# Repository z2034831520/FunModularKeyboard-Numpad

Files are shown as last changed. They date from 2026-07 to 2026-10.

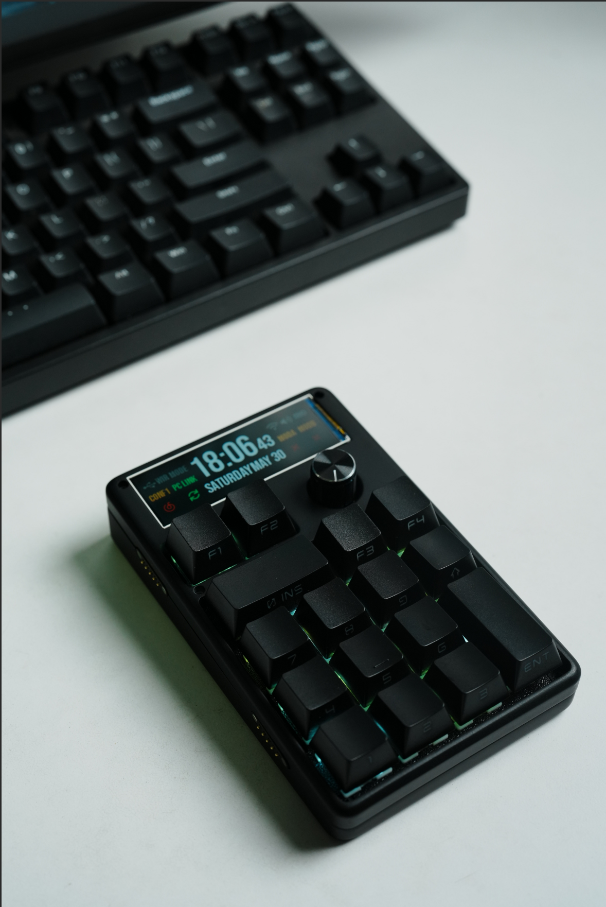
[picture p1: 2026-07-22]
doc/image2.png

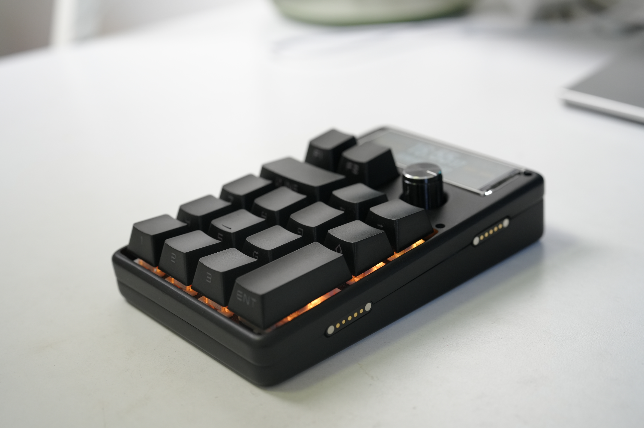
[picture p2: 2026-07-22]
doc/image4.png

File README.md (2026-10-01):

# FunModularKeyboard-Numpad — 独立宏键盘

> 这是 FunModularKeyboard 的独立数字小键盘版本，采用 ESP32-S3，保留可配置键位、屏幕、语音、USB/BLE HID 和 RGB 等功能。




## 🔀 Fork 说明

本项目 Fork 自 [ZhiFun/FunModularKeyboard](https://github.com/ZhiFun/FunModularKeyboard)，当前仓库为 [z2034831520/FunModularKeyboard-Numpad](https://github.com/z2034831520/FunModularKeyboard-Numpad)。

当前定制开发分支为 `standalone-numpad`，基于上游提交 `06c5d73` 继续开发。

该 Fork 目前专注于主机数字小键盘的独立使用。原项目的扩展模块源码和硬件资料仍保留在仓库中，但默认固件不启用这些模块。

### 当前 Fork 的修改

| 修改项 | 说明 |
|---|---|
| 禁用扩展模块 | 通过 `ENABLE_EXTENSION_MODULES=0` 关闭 ModA/ModB 的初始化、轮询和相关界面功能，使固件专注于主机数字小键盘。扩展模块代码未删除，后续仍可重新启用。 |
| 统一源码格式 | 对 `firmware/FunModularKeyboard/src` 下的 C/C++ 源码进行格式统一，不以改变原有功能为目的。 |
| 删除电量检测功能 | 移除 ADC 电压采样、电量估算、校准配置、低电量提示及诊断输出；状态栏不再显示电池图标和百分比。硬件充电功能不受影响。 |

---

屏幕截图 2026-07-19 162423

屏幕截图 2026-07-18 232027

屏幕截图 2026-07-18 231906

屏幕截图 2026-07-18 232058

屏幕截图 2026-07-19 162929

---

## 📖 项目概述

**FunModularKeyboard** 是一款高度可定制的宏键盘，由 **1 个主模块和 2 个磁吸扩展模块**组成。主模块通过磁吸 Pogo-Pin 接口与扩展模块进行 I²C 通信，并支持热插拔。

### 🧩 硬件架构

| 模块 | MCU | 说明 |
|---|-----|---|
| **主模块** | ESP32-S3 | TFT LCD 屏幕、16 键矩阵、旋转编码器、扬声器、MEMS 麦克风、锂电池、RGB LED 和磁吸主机接口 |
| **A 模块（ModA）** | STM8S103F3 | 3 个旋转编码器和 2 个滑动电位器，通过磁吸接口进行 I²C 通信 |
| **B 模块（ModB）** | ESP32-S3 | 基于 [SmartKnob](https://github.com/scottbez1/smartknob)，集成无刷电机旋钮、应变片按压检测和 LED 灯环，通过磁吸接口进行 I²C 通信 |

```
┌─────────────────────────────────────────────┐
│              主模块 (ESP32-S3)              │
│  ┌─────┐  ┌──────────┐  ┌────────────────┐  │
│  │ TFT │  │ 16 键    │  │   旋转编码器   │  │
│  │ LCD │  │ 矩阵     │  │    + 按键      │  │
│  └─────┘  └──────────┘  └────────────────┘  │
│  ┌─────┐  ┌──────┐  ┌──────┐  ┌─────────┐  │
│  │麦克风│  │扬声器│  │ RGB  │  │  电池   │  │
│  └─────┘  └──────┘  └──────┘  └─────────┘  │
│         ┌──────┐  ┌──────┐                  │
│         │ USB  │  │ BLE  │    双模 HID     │
│         └──────┘  └──────┘                  │
│       ══════ 磁吸 Pogo-Pin 接口 ══════       │
│           I²C + 电源 + UART                 │
├──────────────────┬──────────────────────────┤
│  A 模块 (STM8)   │  B 模块 (ESP32-S3)       │
│  3× 旋转编码器  │  无刷电机旋钮 (FOC)       │
│  2× 滑块        │  应变片按压检测          │
│                  │  8× LED 灯环             │
└──────────────────┴──────────────────────────┘
```

---

## ✨ 功能特性

### ⌨️ 键盘

- **8 套可切换键位配置** — 通过旋转编码器随时切换，适配不同工作流程
- **宏组合键** — 按下一个键即可触发多键组合，例如使用 `Ctrl+Win+D` 显示桌面
- **多媒体控制** — 支持播放/暂停、音量调节和切换曲目等操作
- **USB HID + BLE 双模** — 支持有线和无线两种连接方式

### 🎤 语音

- **语音指令** — 长按 MIC 键后说出指令，通过百度语音识别触发预设操作，例如“打开 Spotify”
- **语音转文字** — 将语音输入转换为文字并发送到电脑
- 支持自定义关键词与脚本的绑定关系

### 💻 桌面配套应用

桌面配置工具通过 WiFi/TCP 与键盘通信，支持以下功能：

- 🗺️ **可视化键位编辑器** — 通过拖放配置按键功能
- ⚙️ **设备设置** — 配置 WiFi、RGB 效果、屏幕亮度、主题和音量等参数
- 📜 **脚本引擎** — 支持 Python 脚本，可一键启动应用或执行桌面自动化
- 🔄 **固件 OTA 升级** — 通过无线网络升级键盘固件
- 📊 **电脑状态监控** — 在键盘屏幕上实时显示 CPU 使用率和磁盘空间等信息
- 🎵 **音乐歌词同步** — 播放音乐时同步显示歌词
- 🏠 **HomeAssistant 集成** — 预留智能家居控制接口

### 🎨 显示与灯效

- **TFT LCD + LVGL** — 提供丰富的图形界面和多主题支持
- **16 颗 WS2812B RGB LED** — 支持彩虹、火焰、流星和脉冲等灯效
- **音乐频谱可视化** — 实时显示 FFT 音频频谱动画
- **状态栏** — 显示连接模式、WiFi、音量和录音状态，不再显示电量

### 🧲 扩展模块

> 当前 `standalone-numpad` 分支已默认禁用扩展模块，以下为上游项目保留的硬件能力。

- **A 模块** — 配备 3 个编码器和 2 个滑块，适合调色、混音和视频编辑
- **B 模块** — 配备无刷电机旋钮（SimpleFOC）、触觉反馈和应变片按压检测
- 扩展模块通过磁吸接口实现**即插即用**和自动检测

---

## 📁 项目结构

```
FunModularKeyboard-Numpad/
├── firmware/                         # 固件源码
│   ├── FunModularKeyboard/           # 主模块固件（ESP32-S3、Arduino）
│   │   ├── src/                      # 核心源码
│   │   │   ├── main.cpp              # 程序入口
│   │   │   ├── MainTask.cpp/h        # 主任务调度
│   │   │   ├── DisplayTask.cpp/h     # LVGL 显示任务
│   │   │   ├── MatrixScanner.cpp/h   # 按键矩阵扫描
│   │   │   ├── RotaryEncoder.cpp/h   # 旋转编码器驱动
│   │   │   ├── RGBLightControl.cpp/h # RGB LED 灯效控制
│   │   │   ├── USBKeyboardImpl.cpp/h # USB HID 键盘实现
│   │   │   ├── BLEKeyboardImpl.cpp/h # BLE 键盘实现
│   │   │   ├── VoiceRecognizer.cpp/h # 百度 ASR 语音识别
│   │   │   ├── AudioAnalyzer.cpp/h   # FFT 音频频谱分析
│   │   │   ├── Mic.cpp/h             # MEMS 麦克风驱动
│   │   │   ├── Speaker.cpp/h         # 扬声器驱动
│   │   │   ├── SerialProtocol.cpp/h  # 上位机通信协议
│   │   │   ├── Configuration.cpp/h   # 配置文件管理
│   │   │   ├── Upgrade.cpp/h         # OTA 固件升级
│   │   │   ├── LogManager.cpp/h      # 日志系统
│   │   │   └── modules/              # I²C 主控与扩展模块
│   │   ├── data/                     # SPIFFS 数据文件
│   │   │   ├── config.ini            # 默认配置
│   │   │   └── keymap1~8.ini         # 8 套键位配置
│   │   └── platformio.ini            # PlatformIO 构建配置
│   ├── FunModularKeyboard_ModA/      # A 模块固件（STM8S103F3、IAR）
│   │   ├── main.c                    # 主程序
│   │   ├── ec11.c/h                  # EC11 编码器驱动
│   │   ├── adc.c/h                   # ADC 滑块采样
│   │   ├── i2c.c/h                   # I²C 从机通信
│   │   └── Uart.c/h                  # UART 调试输出
│   └── FunModularKeyboard_ModB/      # B 模块固件（ESP32-S3、PlatformIO）
│       └── firmware/src/             # 基于 SmartKnob 修改的固件
├── electronics/                      # PCB 设计（立创 EDA / EasyEDA）
│   ├── MainBoard/                    # 主板 PCB 工程
│   ├── ModA/                         # A 模块 PCB 工程
│   └── ModB/                         # B 模块 PCB 工程
├── cad/                              # 3D 机械结构文件
│   ├── Top.step / Bottom.step        # 主机外壳上下盖
│   ├── Plate.step                    # 轴体定位板
│   ├── Keycap.step / Keycap2.step    # 键帽
│   ├── FunModularKeyboard.3mf        # 3D 打印工程文件
│   ├── ModA/                         # A 模块外壳
│   └── ModB/                         # B 模块外壳
├── software/scripts/                 # 桌面自动化脚本
│   ├── desktop_automation_launch_apps_template.py  # 一键启动应用模板
│   └── desktop_automation_long_press_shutdown.py   # 长按关机脚本
├── tools/                            # 工具目录
└── README.md
```

---

## 🔧 技术栈

| 类别 | 技术 |
|---|---|
| **主控 MCU** | ESP32-S3（240 MHz、320 KB RAM、8 MB Flash） |
| **A 模块 MCU** | STM8S103F3 |
| **B 模块 MCU** | ESP32-S3 |
| **开发框架** | Arduino（PlatformIO）/ IAR（STM8） |
| **图形界面库** | LVGL 8.3 + TFT_eSPI |
| **键盘协议** | USB HID（TinyUSB）+ BLE HID |
| **语音识别** | 百度语音识别 API（REST） |
| **电机控制** | SimpleFOC 2.3 |
| **通信方式** | I²C（模块间）/ WiFi TCP（上位机） |
| **文件系统** | SPIFFS |
| **RGB 驱动** | FastLED（WS2812B） |
| **FFT 分析** | arduinoFFT |

### 主要库依赖

```
ESP32 BLE Keyboard    — BLE HID 键盘
FastLED               — RGB LED 控制
TFT_eSPI              — TFT 屏幕驱动
lvgl                  — 嵌入式图形界面框架
ESP32-audioI2S        — I²S 音频输入
SimpleIni             — INI 配置文件解析
ArduinoJson           — JSON 序列化
arduinoFFT            — 快速傅里叶变换
SimpleFOC             — FOC 电机控制
TLV493D               — 3D 磁场传感器
```

---

## 🚀 快速开始

### 主模块固件

1. 安装 [PlatformIO IDE](https://platformio.org/install)（VS Code 扩展）。

2. 克隆本 Fork 的 `standalone-numpad` 分支，然后进入主模块固件目录。

```bash
git clone --branch standalone-numpad https://github.com/z2034831520/FunModularKeyboard-Numpad.git
cd FunModularKeyboard-Numpad/firmware/FunModularKeyboard
```

3. 配置 WiFi 和百度语音 API 凭据（编辑 `data/config.ini` 或通过串口配置）。

4. 编译并烧录。

```bash
# 编译固件
pio run

# 烧录固件并上传 SPIFFS 数据
pio run --target upload
pio run --target uploadfs
```

### A 模块固件

使用 **IAR for STM8** 打开 `firmware/FunModularKeyboard_ModA/RGB_INIT.eww`，然后编译并烧录。

### B 模块固件

```bash
cd FunModularKeyboard-Numpad/firmware/FunModularKeyboard_ModB
pio run --target upload
```

> A/B 扩展模块固件由上游项目保留。当前独立数字小键盘模式不需要编译或烧录这两部分。

### 引脚参考

主模块的主要引脚分配如下，完整定义请参考 `platformio.ini` 和源码。

| 功能 | GPIO |
|---|---|
| LED 数据 | 6 |
| LED 电源 | 36 |
| 编码器 CLK | 5 |
| 编码器 DT | 21 |
| 编码器按键 SW | 9 |
| 电池电压 ADC（当前固件未使用） | 4 |
| I²C SDA | 15 |
| I²C SCL | 8 |
| 按键矩阵行 | 48, 10, 47, 33, 14 |
| 按键矩阵列 | 35, 34, 7, 13 |

---

## 🎮 使用指南

### 键位配置

1. 通过 WiFi 连接桌面配套应用。
2. 使用可视化拖放编辑器为每个按键分配功能，包括单键、组合键、宏和媒体控制等。
3. 最多可配置 8 套键位方案，长按旋转编码器即可切换。

### 语音功能

1. 在配套应用中配置百度 API Key 和 Secret Key。
2. 长按映射为 MIC 的按键开始录音。
3. 系统将识别结果与预设关键词匹配，并触发对应脚本。

### 固件升级

1. 配套应用通过 WiFi 将新固件推送到键盘。
2. 键盘自动重启进入 OTA 模式并完成升级。

---

## 🏗️ 硬件制作

- **PCB**：使用[立创 EDA](https://pro.lceda.cn/) 打开 `electronics/` 目录下的 `.epro2` 工程文件。
- **3D 外壳**：`cad/` 目录中提供 STEP 机械结构文件和可直接打印的 3MF 文件。
- **磁吸接口**：使用 Pogo-Pin 弹簧触点，用于模块间的 I²C 通信和供电。

---

## 📝 开发计划

- [ ] 开源桌面配套配置应用
- [ ] 接收社区贡献的扩展模块
- [ ] 完整集成 HomeAssistant
- [ ] 支持宏录制与回放
- [ ] 支持更多语音识别引擎
- [ ] 完善英文项目文档

---

## 🤝 参与贡献

欢迎提交 Issue 和 Pull Request。如果你设计了有趣的扩展模块，也欢迎在这里分享。

---

## 🙏 致谢

- [ZhiFun/FunModularKeyboard](https://github.com/ZhiFun/FunModularKeyboard) — 本 Fork 的上游项目
- [SmartKnob](https://github.com/scottbez1/smartknob) — 优秀的开源触觉反馈旋钮项目
- [LVGL](https://lvgl.io/) — 轻量级嵌入式图形界面库
- [PlatformIO](https://platformio.org/) — 跨平台嵌入式开发生态
- [百度语音识别](https://ai.baidu.com/tech/speech) — 中文语音识别服务

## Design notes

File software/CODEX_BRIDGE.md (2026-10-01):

# 键盘与桌面 Codex 双向互动

键盘通过主板串口发送动作，电脑端 `codex_bridge.py` 再通过本机 Codex App Server
创建线程和任务。桌面 Codex 的生命周期 Hook 通过本机 UDP 将运行、审批与完成状态
发送给桥接器，再由桥接器统一回传到 LCD 和 RGB 灯效。

## 全局安装（推荐）

在仓库根目录运行：

```powershell
powershell -ExecutionPolicy Bypass -File software\install_codex_bridge.ps1
```

安装程序会把桥接器复制到 `%USERPROFILE%\.codex\keyboard-bridge`，将用户级 Hook
安装到 `%USERPROFILE%\.codex\hooks.json`，并注册登录自启动任务
`FunModularKeyboard Codex Bridge`。计划任务会直接托管桥接进程，并在异常退出后每分钟
自动重试。用户级 Hook 会覆盖所有 Codex 工作目录；首次安装或
Hook 内容变化后，需要在 Codex 中打开 `/hooks` 审核并信任新的用户级 Hook。

如果登录后桥接器没有运行，可直接双击仓库根目录的
`start_codex_keyboard_bridge.cmd`。它会复用同一个计划任务，避免重复启动，并在失败时显示
错误。运行日志保存在 `%USERPROFILE%\.codex\keyboard-bridge\logs\codex_bridge.log`。

Hook 会把每个会话的 `cwd` 一并发送给桥接器。LCD/RGB 会汇总所有项目的任务状态。
K10 会通过 Windows 注册的 `codex://threads/new` 链接打开桌面 Codex 的新任务页；
串口号默认通过 `CX<PING`/`CX>PONG` 协议自动探测，因此
CH340 的 COM 编号变化后通常不需要重新配置。

仓库自身的 `.codex/hooks.json` 可以保留，方便其他用户直接使用。当前仓库同时加载
项目级与用户级 Hook 时会出现重复事件，但桥接器会按会话和轮次去重，不会重复计算任务。

## 默认按键

| 按键 | 动作 |
| --- | --- |
| K10 | 唤起桌面 Codex，并打开一个用户可见的新任务页 |
| K11 | 暂停当前桥接器任务 |
| K12 | 同意当前唯一一项待审批操作；没有待审批时无效 |
| K13 | 拒绝待审批操作；没有待审批时无效 |
| K14 | 在原线程中继续被暂停的桥接器任务 |

旋钮默认仍控制电脑音量：旋转调节音量、短按静音。长按旋钮约 0.7 秒可在音量模式和
Codex 思考等级模式之间切换；进入思考等级模式后，旋转会按照当前模型实际支持的等级
循环切换，短按旋钮也会切换到下一个等级。没有 `E:` 标记时，旋钮处于音量模式。

旋钮通过 Codex App Server 保存用户级默认 `model_reasoning_effort`，并读取当前工作目录下
的有效本地配置。这只能证明磁盘配置已更新，不能证明桌面 GUI 的等级选择器或正在运行的
任务已经改变。项目级配置等更高优先级设置可能覆盖用户级默认值。

K10 打开新任务页后，仅在没有已知运行任务时尝试通过 Windows UI Automation 的语义控件
选择等级，并重新读取模型与等级进行确认。不会点击固定坐标、自动提交任务或操作审批。
找不到唯一的模型和等级控件时会放弃自动控制，保留任务状态及 RGB 联动。
启动、旋钮选择及周期检查只读取 GUI，不会自动修改已有任务的选择器。

思考等级模式下，`E:?` 表示桌面端等级尚未确认；只有处于 READY 且当前 GUI 选择器的模型
和等级均匹配时，才显示 `E:HIGH` 等标记。此标记仍不证明任务运行时实际使用的等级。
运行中的 GUI 任务不提供可核验的等级字段，因此显示 `E:?`，LCD/RGB 继续汇总任务状态。
若当前桌面版本无法识别控件，请手动在桌面新任务页选择等级，不要仅依据磁盘配置判断生效。

上述 `E:?` 语义需要配套固件：旧固件在状态消息省略等级时会保留旧等级，并导致桥接器
收不到匹配回执而重发。更新桥接脚本后还需烧录修正后的固件；没有烧录时请以电脑端报告
为准，不要把 LCD 上残留的等级当作确认结果。

可从仓库根目录执行只读兼容性检查（不打开串口、不修改桌面）：

```powershell
py software\codex_bridge.py --desktop-probe --probe-model gpt-5.6-sol --probe-effort high
```

查看旋钮选择、本地有效配置和 GUI 确认结果：

```powershell
powershell -ExecutionPolicy Bypass -File software\show_codex_effort.ps1
```

加 `-Watch` 可持续查看。报告保存于 `%USERPROFILE%\.codex\keyboard-bridge\effort-state.json`。
`saved_host_hint` 只是桌面保存的主机提示，不是当前任务执行位置的证据；
`RuntimeVerified` 当前始终为 false。启动桥接器时加 `--no-desktop-sync` 可关闭 GUI 检测与尝试，
不影响 Hook 状态联动。

开发回归检查：`py -B -m unittest software/test_codex_bridge.py software/test_codex_desktop.py`。
串口固件回归测试位于 `software/tests/codex_serial`，使用模拟串口编译实际的
`CodexSerialBridge.cpp`，验证旧等级清除、回执、心跳和断连语义，不需要连接硬件。

## 使用方法

1. 确认桌面 Codex 已登录，并且 PowerShell 中执行 `codex --version` 能找到 Codex CLI。
2. 将键盘设为有线模式，烧录固件，并单独上传 `data` 分区，让 `keymap1.ini` 的映射生效。
3. 安装 Python 依赖：

   ```powershell
   py -m pip install -r software\requirements-codex-bridge.txt
   ```

4. 关闭占用键盘 CDC 串口的串口监视器，然后从仓库根目录启动桥接器：

   ```powershell
   py software\codex_bridge.py --port COM50
   ```

   请把 `COM50` 替换成主板 CH340 当前对应的端口。当前固件的烧录与 Codex
   通信共用该端口，因此启动桥接器前必须关闭 PlatformIO 串口监视器；需要重新
   烧录时，也必须先退出桥接器释放串口。

5. 重新打开 Codex 桌面端中的项目。首次加载 `.codex/hooks.json` 时，在 Codex 的
   Hook 管理界面审核并信任这些项目级 Hook。Hook 未被信任时，键盘按键发起的任务
   仍可联动，但桌面端主动发起的任务不会回传状态。

桥接器通过 App Server 发起的分析、审查等任务默认限制在当前仓库，使用
`workspace-write` 沙箱、`on-request` 审批，并关闭任务网络访问。LCD 显示
`CODEX READY` 后才接受任务键。K10 不再创建后台 App Server 任务，而是直接打开桌面
Codex 的新任务页；输入任务并发送后，Hook 才会让 LCD/RGB 进入运行状态。若本机未注册
`codex://` 链接，K10 会显示错误状态。`--no-open-app` 只关闭桥接器线程的自动展示，
不会禁用 K10 的桌面新任务入口。

可先执行不连接硬件、不启动 App Server 的配置检查：

```powershell
py software\codex_bridge.py --dry-run
```

`codex_tasks.json` 中的 `RESUME` 可以修改 K14 对应的提示词。K10 只打开桌面新任务页，
不会自动填入或提交提示词。桥接程序必须保持运行；退出后 LCD
会在心跳超时后显示 `CODEX OFF`。

桌面端 Hook 默认向 `127.0.0.1:18765` 发送状态。若端口被其他程序占用，可用
`--hook-port` 修改桥接器监听端口，并在 `.codex/hooks.json` 的命令中为
`codex_status_hook.py` 传入相同的 `--port`。Hook 不直接打开串口，因此不会与桥接器
争用 COM50。

桌面端任务的审批灯效只用于提示。K12/K13 仍只能处理由键盘桥接器自身发起的审批；
桌面端发起的审批需要在桌面 Codex 中确认或拒绝。

## RGB 状态

| Codex 状态 | RGB 灯效 |
| --- | --- |
| 已连接并待机 | 青色呼吸 |
| 正在运行 | 蓝色流水 |
| 等待审批 | 橙色闪烁 |
| 任务暂停 | 黄色双闪，保持到 K14 继续或 K10 新建任务 |
| 任务完成 | 绿色常亮，随后恢复青色呼吸 |
| 发生错误 | 红色快速闪烁 |
| 桥接器断开 | 恢复键盘原有 RGB 配置 |

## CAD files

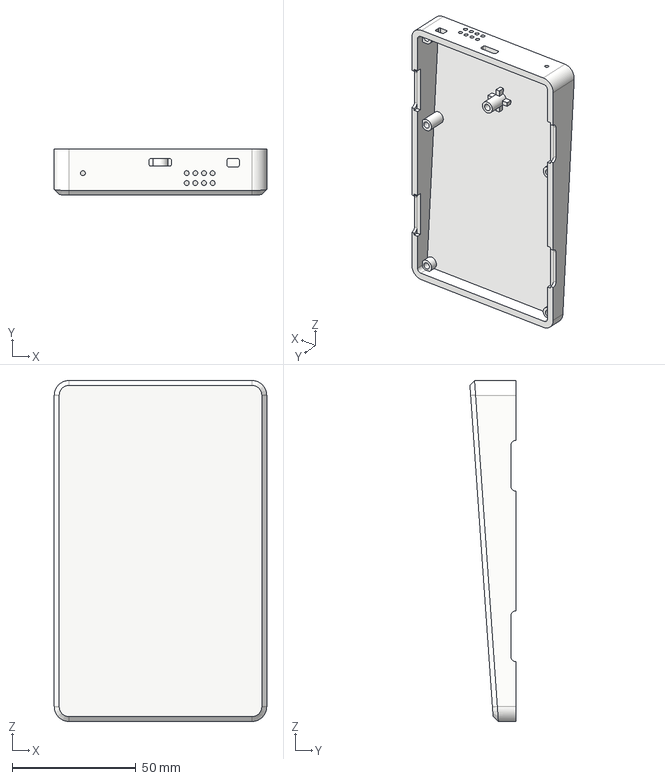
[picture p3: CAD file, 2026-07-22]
cad/Bottom.step
86.0 x 18.7 x 138.0 mm

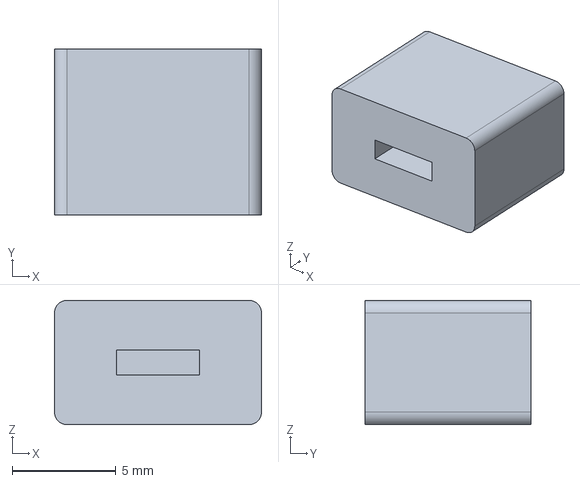
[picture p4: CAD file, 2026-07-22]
cad/ModA/Slider_Hat.step
10.0 x 8.00 x 6.00 mm

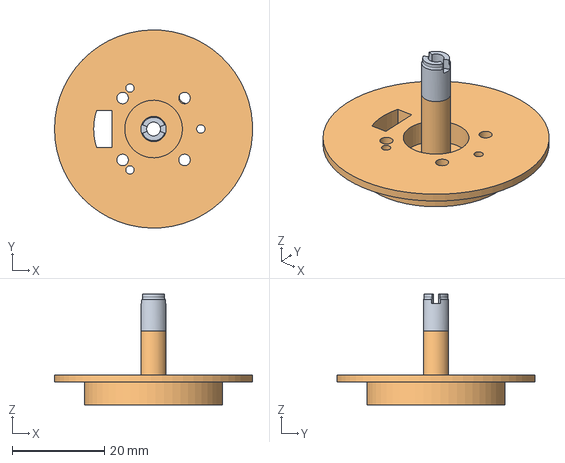
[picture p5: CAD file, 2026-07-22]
cad/ModB/MountBase_mod.step
43.0 x 43.0 x 24.0 mm

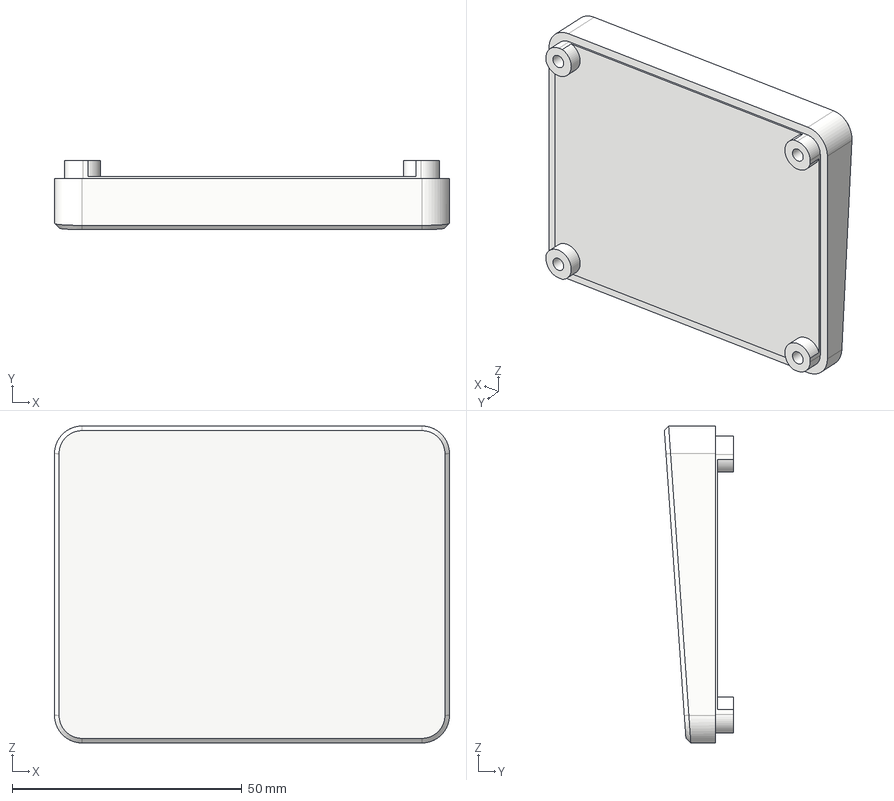
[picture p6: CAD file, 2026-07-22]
cad/ModA/ModA_Bottom.step
86.0 x 15.1 x 69.0 mm

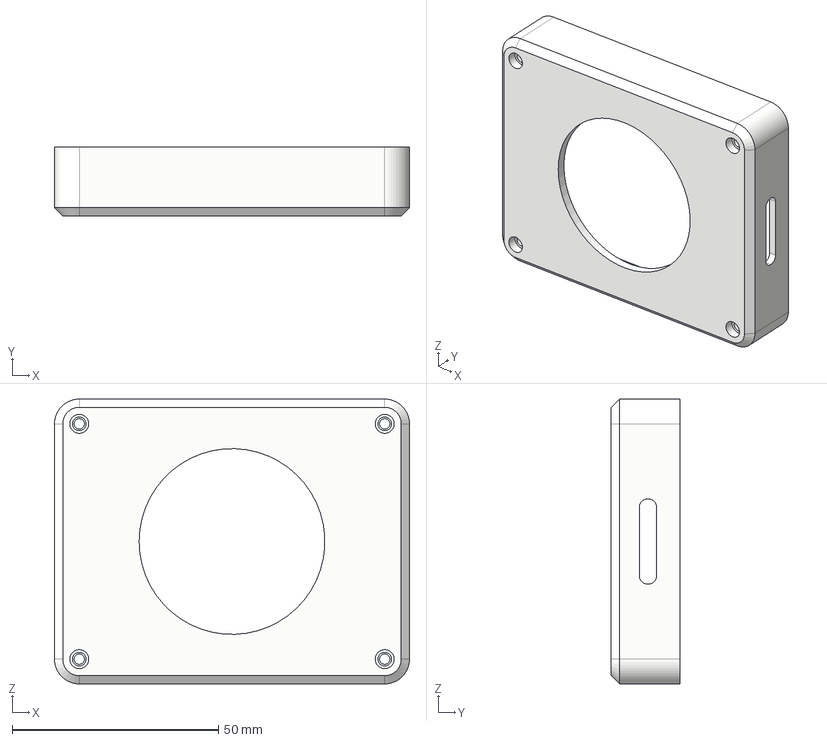
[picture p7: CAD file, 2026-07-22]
cad/ModB/ModB_Top.step
86.0 x 16.6 x 69.0 mm

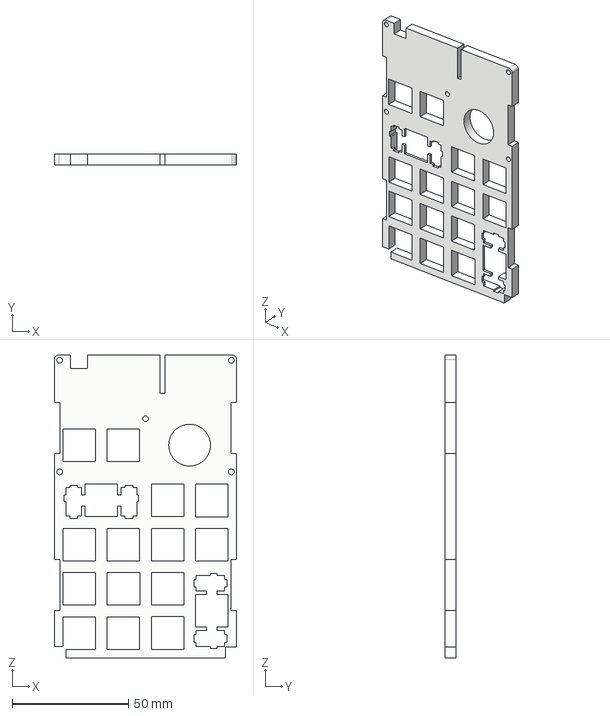
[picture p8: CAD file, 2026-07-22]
cad/Plate.step
78.6 x 4.80 x 130.6 mm

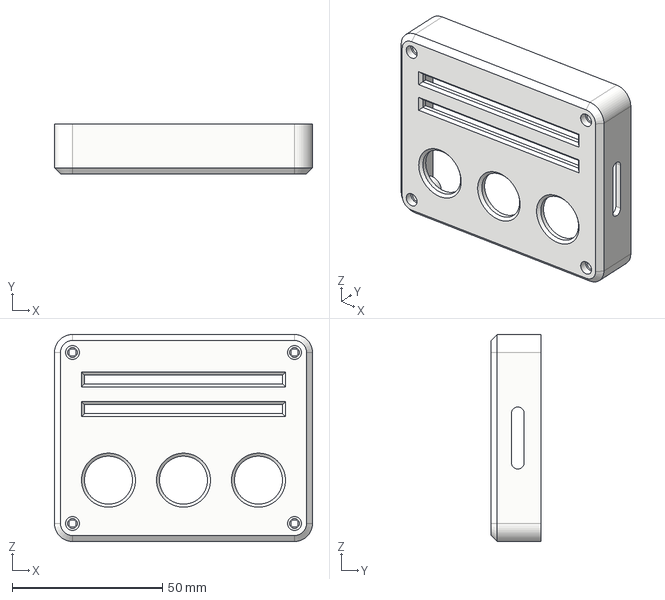
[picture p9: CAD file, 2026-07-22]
cad/ModA/ModA_Top.step
86.0 x 16.6 x 69.0 mm

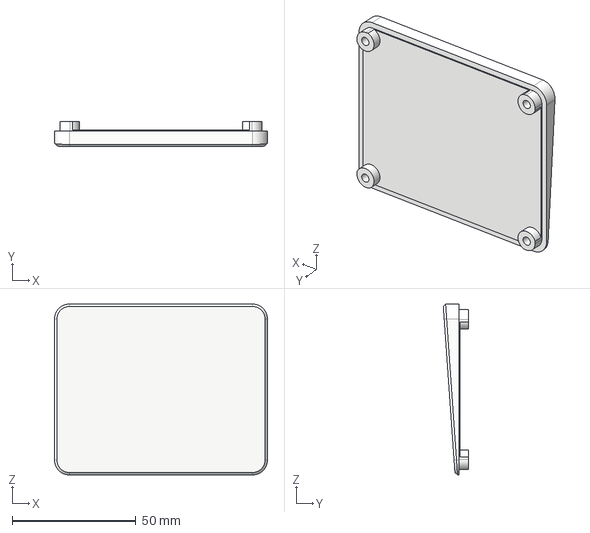
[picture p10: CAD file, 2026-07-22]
cad/ModB/ModB_Bottom.step
86.0 x 10.3 x 69.0 mm

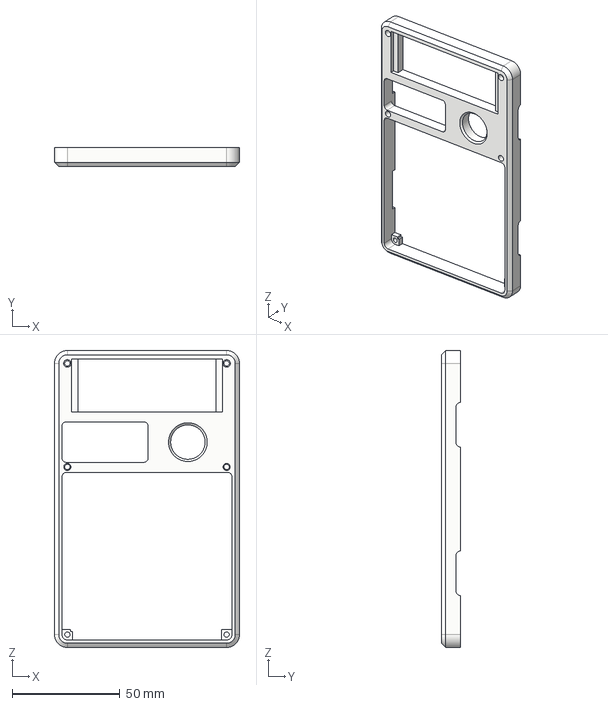
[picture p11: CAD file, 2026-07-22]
cad/Top.step
86.0 x 8.90 x 138.0 mm

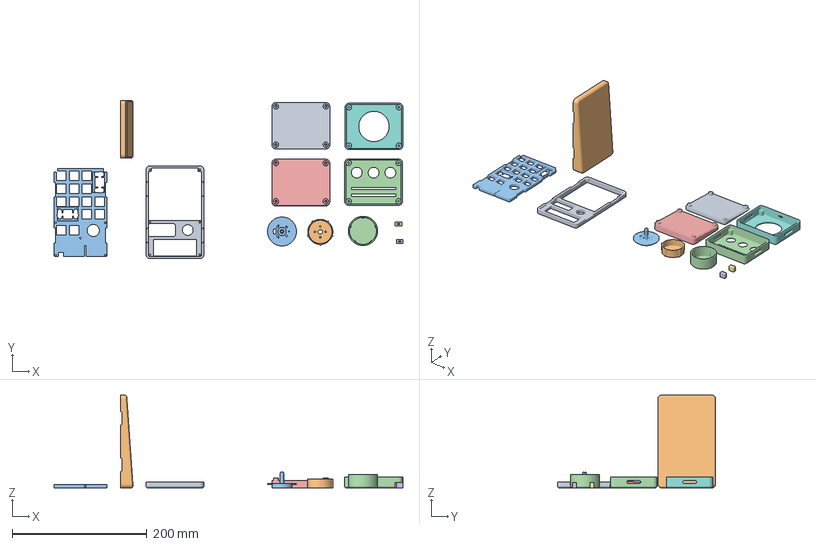
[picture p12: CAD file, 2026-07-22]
cad/FunModularKeyboard.3mf
518.1 x 235.2 x 138.0 mm
Top.step
Bottom.step
Plate.step
ModA_Top.step
ModA_Bottom.step
Slider_Hat.step x 2
ModB_Top.step
ModB_Bottom.step
MotorBase.step
MountBase_mod.step
ModB_Hat.step

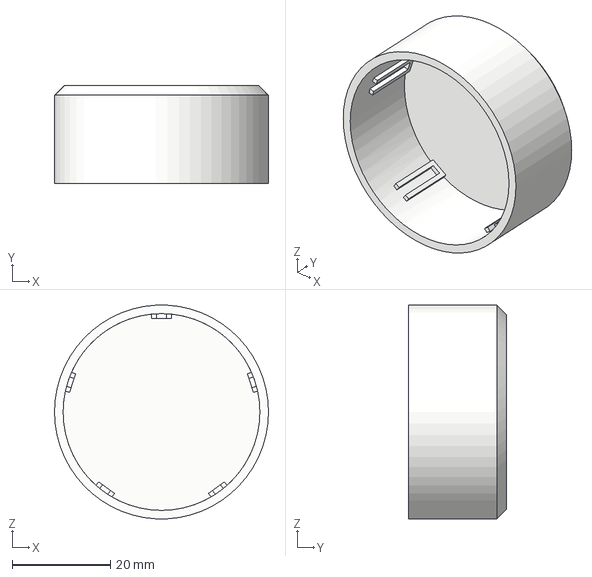
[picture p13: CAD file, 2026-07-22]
cad/ModB/ModB_Hat.step
43.5 x 20.0 x 43.4 mm

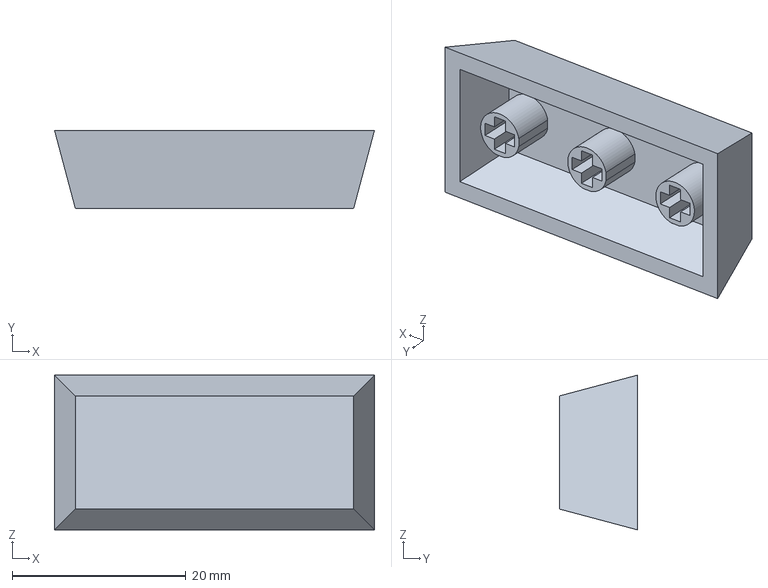
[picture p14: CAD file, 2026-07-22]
cad/Keycap2.step
36.8 x 9.00 x 17.8 mm

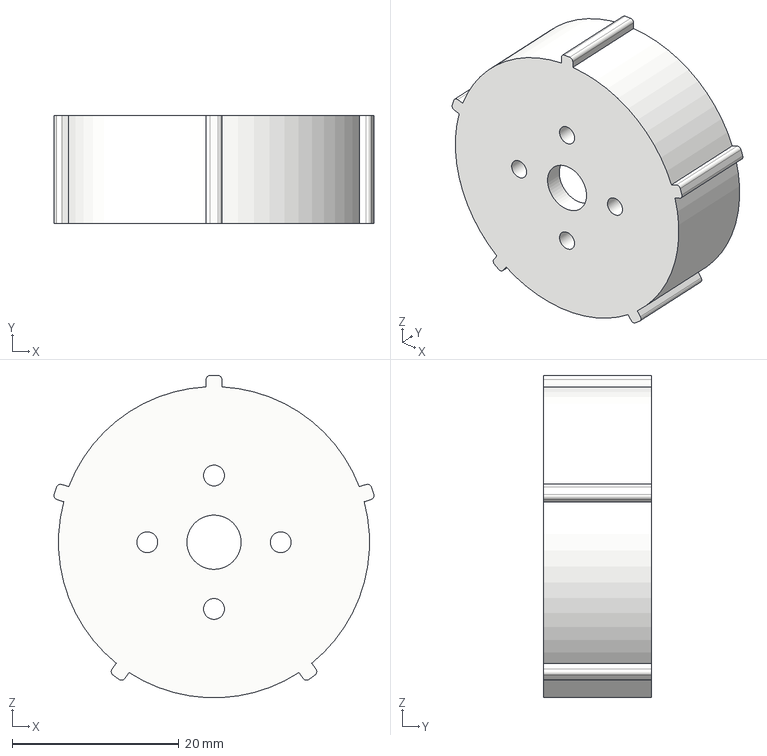
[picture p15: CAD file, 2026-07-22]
cad/ModB/MotorBase.step
38.4 x 13.0 x 38.6 mm

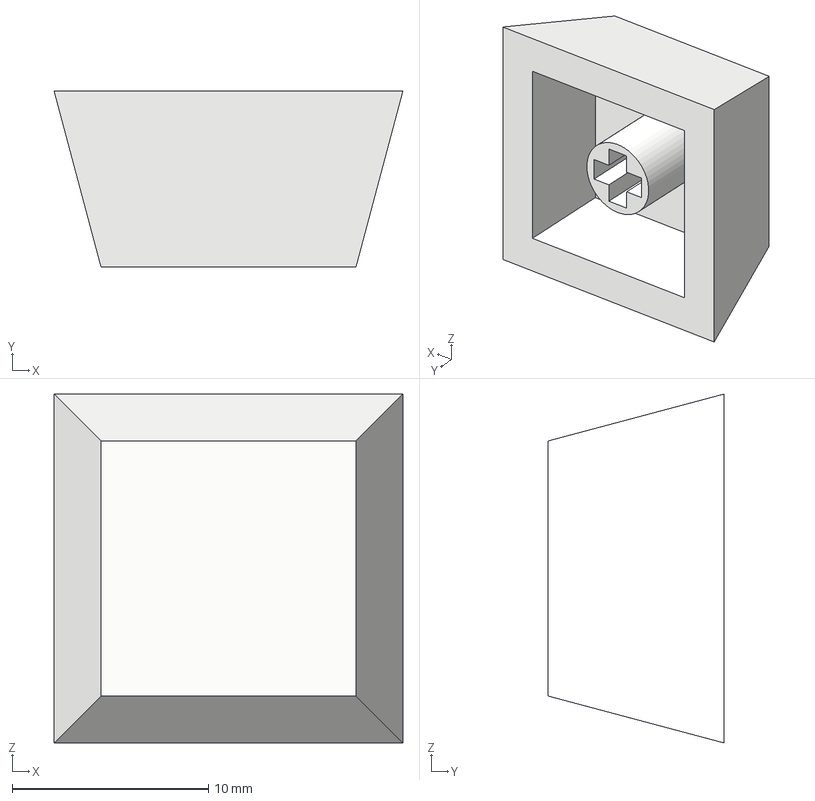
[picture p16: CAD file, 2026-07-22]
cad/Keycap.step
17.8 x 9.00 x 17.8 mm

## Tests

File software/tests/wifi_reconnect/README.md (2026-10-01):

# WiFi reconnect regression

Run from the repository root:

```powershell
py -B -m unittest software/test_wifi_reconnect.py
```

Requires `g++` on PATH. The test extracts the actual connection and retry methods
from `MainTask.cpp`, compiles them with fake WiFi and clock dependencies, and runs
the resulting executable in a temporary directory.

Coverage: stale CONNECT_FAILED/NO_SSID/NO_SHIELD results do not cancel a new scan;
the 10-second timeout and 5-second retry delay remain bounded; a restored network
can connect; disabled WiFi and BLE mode do not connect; deliberate retry cleanup
does not overwrite a useful disconnect reason; event registration is not repeated.

This is a deterministic firmware logic test, not proof of real hotspot connectivity.
After flashing, verify startup and restoring a previously unavailable hotspot on
the device. No SSID, password, or device data partition is modified by the test.

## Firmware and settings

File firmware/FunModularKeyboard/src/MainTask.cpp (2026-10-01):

#include "MainTask.h"
#include "BLEKeyboardImpl.h"
#include "USBKeyboardImpl.h"
#include "SystemTime.h"
#include <ctype.h>
#include <time.h>

#include <WiFi.h>
#include "esp_attr.h"
#include "esp_bt.h"
#include "esp_heap_caps.h"
#include "lwip/apps/sntp.h"

#define configCHECK_FOR_STACK_OVERFLOW 2 // 启用 FreeRTOS 堆栈溢出检测

/**************************************************************************/
// 通过网络获取时间
// NTP 配置
RTC_DATA_ATTR uint32_t g_bleTimeSyncRestartMarker = 0;

namespace
{
    constexpr const char *kVoiceTriggerFunctionKey = "KEY_FUNCTION_ASR";
    constexpr const char *kGeminiFunctionKey = "KEY_FUNCTION_GEMINI";
    constexpr const char *kGeminiUrl = "https://gemini.google.com/app";
    constexpr const char *kClashVergeFunctionKey = "KEY_FUNCTION_CLASH_VERGE";
    constexpr const char *kClashVergeCommand = "\"F:\\Clash Verge\\clash-verge.exe\"";
    constexpr const char *kMediaVolumeUp = "KEY_MEDIA_VOLUME_UP";
    constexpr const char *kMediaVolumeDown = "KEY_MEDIA_VOLUME_DOWN";
    constexpr const char *kMediaMute = "KEY_MEDIA_MUTE";
    constexpr const char *kCodexNewTaskFunctionKey = "KEY_FUNCTION_CODEX_NEW_TASK";
    constexpr const char *kCodexPauseFunctionKey = "KEY_FUNCTION_CODEX_PAUSE";
    constexpr const char *kCodexResumeFunctionKey = "KEY_FUNCTION_CODEX_RESUME";
    constexpr const char *kCodexAnalyzeFunctionKey = "KEY_FUNCTION_CODEX_ANALYZE";
    constexpr const char *kCodexReviewFunctionKey = "KEY_FUNCTION_CODEX_REVIEW";
    constexpr const char *kCodexAcceptFunctionKey = "KEY_FUNCTION_CODEX_ACCEPT";
    constexpr const char *kCodexDeclineFunctionKey = "KEY_FUNCTION_CODEX_DECLINE";
    constexpr uint8_t kLeftWindowsKey = 0x83;
    constexpr uint8_t kEnterKey = 0xB0;
    constexpr uint8_t kBoost5VEnablePin = 3;
    constexpr uint32_t kWifiRetryIntervalMs = 5000;
    constexpr uint32_t kWifiConnectTimeoutMs = 10000;
    constexpr uint32_t kTimeSyncCheckIntervalMs = 500;
    constexpr uint32_t kTimeSyncRestartIntervalMs = 30000;
    constexpr uint32_t kBluetoothStartupTimeSyncTimeoutMs = 10000;
    constexpr uint32_t kBleTimeSyncRestartMagic = 0x54494D45; // "TIME"
    constexpr const char *kNtpServerPrimary = "0.cn.pool.ntp.org";
    constexpr const char *kNtpServerSecondary = "1.cn.pool.ntp.org";
    constexpr const char *kNtpServerFallback = "pool.ntp.org";

    const char *lookupWindowsLaunchTarget(const String &functionKey)
    {
        if (functionKey.equalsIgnoreCase(kGeminiFunctionKey))
        {
            return kGeminiUrl;
        }
        if (functionKey.equalsIgnoreCase(kClashVergeFunctionKey))
        {
            return kClashVergeCommand;
        }
        return nullptr;
    }

    bool lookupCodexTask(const String &functionKey, CodexTask &task)
    {
        if (functionKey.equalsIgnoreCase(kCodexNewTaskFunctionKey))
        {
            task = CodexTask::NEW_TASK;
            return true;
        }
        if (functionKey.equalsIgnoreCase(kCodexPauseFunctionKey))
        {
            task = CodexTask::PAUSE;
            return true;
        }
        if (functionKey.equalsIgnoreCase(kCodexResumeFunctionKey))
        {
            task = CodexTask::RESUME;
            return true;
        }
        if (functionKey.equalsIgnoreCase(kCodexAnalyzeFunctionKey))
        {
            task = CodexTask::ANALYZE;
            return true;
        }
        if (functionKey.equalsIgnoreCase(kCodexReviewFunctionKey))
        {
            task = CodexTask::REVIEW;
            return true;
        }
        if (functionKey.equalsIgnoreCase(kCodexAcceptFunctionKey))
        {
            task = CodexTask::ACCEPT;
            return true;
        }
        if (functionKey.equalsIgnoreCase(kCodexDeclineFunctionKey))
        {
            task = CodexTask::DECLINE;
            return true;
        }
        return false;
    }

    String normalizeFunctionKey(String key)
    {
        key.trim();
        if (key.startsWith("F:"))
        {
            key = key.substring(2);
            key.trim();
        }
        return key;
    }

    bool hasNonAsciiUtf8(const String &text)
    {
        for (size_t i = 0; i < text.length(); ++i)
        {
            if (static_cast<uint8_t>(text[i]) > 0x7F)
            {
                return true;
            }
        }
        return false;
    }

    const char *wifiStatusToText(wl_status_t status)
    {
        switch (status)
        {
        case WL_IDLE_STATUS:
            return "IDLE";
        case WL_NO_SSID_AVAIL:
            return "NO_SSID";
        case WL_SCAN_COMPLETED:
            return "SCAN_COMPLETED";
        case WL_CONNECTED:
            return "CONNECTED";
        case WL_CONNECT_FAILED:
            return "CONNECT_FAILED";
        case WL_CONNECTION_LOST:
            return "CONNECTION_LOST";
        case WL_DISCONNECTED:
            return "DISCONNECTED";
        case WL_NO_SHIELD:
            return "NO_SHIELD";
        default:
            return "UNKNOWN";
        }
    }

    constexpr bool shouldFinishWiFiAttempt(wl_status_t status, uint32_t elapsedMs)
    {
        // begin() returns shared asynchronous status, possibly from an earlier
        // attempt. Give every new scan its full window before cancelling it.
        return status != WL_CONNECTED && elapsedMs >= kWifiConnectTimeoutMs;
    }

    static_assert(!shouldFinishWiFiAttempt(WL_NO_SSID_AVAIL, 0),
                  "A stale NO_SSID result must not cancel a new WiFi scan");
    static_assert(!shouldFinishWiFiAttempt(WL_CONNECT_FAILED, 4000),
                  "A stale CONNECT_FAILED result must not cancel a new attempt");
    static_assert(shouldFinishWiFiAttempt(WL_NO_SSID_AVAIL, kWifiConnectTimeoutMs),
                  "A failed WiFi attempt must eventually be retried");

    void logHeapSnapshot(const char *stage)
    {
        LOG_INFO("Heap", "%s | free=%u min=%u largest=%u psram=%u",
                 stage,
                 ESP.getFreeHeap(),
                 ESP.getMinFreeHeap(),
                 heap_caps_get_largest_free_block(MALLOC_CAP_8BIT),
                 ESP.getFreePsram());
    }

}

/**************************************************************************/

bool MainTask::hasMappedOutput(const KeyMapping &mapping) const
{
    return !mapping.function_key.isEmpty() || mapping.normal_key_count > 0 || mapping.macros_key_count > 0;
}

void MainTask::triggerMappedInput(const KeyMapping &mapping)
{
    if (!currentKeyboard_ || !hasMappedOutput(mapping))
    {
        return;
    }

    const char *launchTarget = lookupWindowsLaunchTarget(mapping.function_key);
    if (launchTarget != nullptr)
    {
        launchWindowsTarget(launchTarget);
        return;
    }

    for (uint8_t i = 0; i < mapping.macros_key_count; ++i)
    {
        currentKeyboard_->press(mapping.macros_key[i]);
    }

    bool functionPressed = false;
    if (!mapping.function_key.isEmpty() && !mapping.function_key.equals(kVoiceTriggerFunctionKey))
    {
        currentKeyboard_->press(mapping.function_key);
        functionPressed = true;
    }
    else
    {
        for (uint8_t i = 0; i < mapping.normal_key_count; ++i)
        {
            currentKeyboard_->press(mapping.normal_key[i]);
        }
    }

    if (functionPressed)
    {
        currentKeyboard_->release(mapping.function_key);
    }
    else
    {
        for (int i = mapping.normal_key_count - 1; i >= 0; --i)
        {
            currentKeyboard_->release(mapping.normal_key[i]);
        }
    }

    for (int i = mapping.macros_key_count - 1; i >= 0; --i)
    {
        currentKeyboard_->release(mapping.macros_key[i]);
    }
}

// 连接 WiFi
bool MainTask::ConnectToWiFi(const String &ssid, const String &password)
{
    String ssidTrimmed = ssid;
    String passwordTrimmed = password;
    ssidTrimmed.trim();
    passwordTrimmed.trim();

    LOG_DEBUG("Log", "start connect WiFi:");
    LOG_DEBUG("Log", ssidTrimmed);

    if (ssidTrimmed.isEmpty())
    {
        LOG_ERROR("Log", "WiFi SSID is empty");
        wifiReconnectActive_ = false;
        return false;
    }

    if (WiFi.status() == WL_CONNECTED)
    {
        LOG_DEBUG("Log", "WiFi already connected");
        wifiReconnectActive_ = true;
        wifiConnectAttemptStartedMs_ = 0;
        wifiNextRetryAtMs_ = 0;
        return true;
    }

    if (!wifiEventRegistered_)
    {
        // The event callback runs on the WiFi event task: only publish atomic
        // data here. Logging and all connection actions stay on MainTask.
        wifiDisconnectEventHandlerId_ = WiFi.onEvent(
            [this](WiFiEvent_t, WiFiEventInfo_t info)
            {
                const uint16_t reason = info.wifi_sta_disconnected.reason;
                // Do not overwrite a useful error with our own retry cleanup.
                if (reason != WIFI_REASON_ASSOC_LEAVE)
                {
                    wifiLastDisconnectReason_.store(reason);
                    wifiDisconnectEventCount_.fetch_add(1);
                }
            },
            ARDUINO_EVENT_WIFI_STA_DISCONNECTED);
        wifiEventRegistered_ = true;
    }

    WiFi.persistent(false);
    WiFi.setAutoReconnect(true);
    WiFi.setSleep(false);
    WiFi.mode(WIFI_STA);
    WiFi.disconnect(false, false);
    delay(20);

    // Do not interpret begin()'s return value as the outcome of this new
    // asynchronous attempt. The reconnect state machine observes it later.
    WiFi.begin(ssidTrimmed.c_str(), passwordTrimmed.c_str());
    wifiReconnectActive_ = true;
    wifiConnectAttemptStartedMs_ = millis();
    wifiNextRetryAtMs_ = wifiConnectAttemptStartedMs_ + kWifiRetryIntervalMs;

    LOG_INFO("Log", "WiFi connect attempt started: ssid=%s", ssidTrimmed.c_str());
    return true;
}

void MainTask::scheduleWiFiConnectAttempt(bool immediate)
{
    if (!configuration_.settings_.wifi_switch)
    {
        return;
    }

    String ssid = configuration_.settings_.wifi_ssid;
    ssid.trim();
    if (ssid.isEmpty())
    {
        LOG_WARNING("Log", "WiFi switch enabled but SSID is empty, skip reconnect scheduling");
        wifiReconnectActive_ = false;
        wifiConnectAttemptStartedMs_ = 0;
        wifiNextRetryAtMs_ = 0;
        return;
    }

    wifiReconnectActive_ = true;
    wifiConnectAttemptStartedMs_ = 0;
    wifiNextRetryAtMs_ = immediate ? 0 : millis() + kWifiRetryIntervalMs;
}

void MainTask::stopWiFiReconnect()
{
    wifiReconnectActive_ = false;
    wifiWasConnected_ = false;
    wifiConnectAttemptStartedMs_ = 0;
    wifiNextRetryAtMs_ = 0;
    timeSyncPending_ = false;
    timeSyncStartedMs_ = 0;
    timeSyncNextCheckMs_ = 0;
    WiFi.disconnect(true, true);
    WiFi.mode(WIFI_OFF);
}

void MainTask::onWiFiConnected()
{
    LOG_INFO("Log", "WiFi connected, IP=%s, RSSI=%d", WiFi.localIP().toString().c_str(), WiFi.RSSI());
    wifiConnectAttemptStartedMs_ = 0;
    wifiNextRetryAtMs_ = 0;
    StartTimeSync();
    reconcileVoiceRuntimeState();
}

void MainTask::processWiFiReconnect(uint32_t nowMs)
{
    const uint32_t eventCount = wifiDisconnectEventCount_.load();
    if (eventCount != wifiReportedDisconnectEventCount_)
    {
        wifiReportedDisconnectEventCount_ = eventCount;
        const uint16_t reason = wifiLastDisconnectReason_.load();
        if (reason != WIFI_REASON_ASSOC_LEAVE)
        {
            LOG_WARNING("Log", "WiFi disconnect event: reason=%u(%s)",
                        static_cast<unsigned>(reason),
                        WiFi.disconnectReasonName(static_cast<wifi_err_reason_t>(reason)));
        }
    }

    if (!configuration_.settings_.wifi_switch || currentWorkMode_ == Configuration::BLUETOOTH_KEYBOARD_MODE)
    {
        if (wifiWasConnected_ || WiFi.getMode() != WIFI_OFF)
        {
            stopWiFiReconnect();
            if (currentWorkMode_ == Configuration::BLUETOOTH_KEYBOARD_MODE)
            {
                LOG_WARNING("Log", "WiFi disabled in BLE mode due memory limits");
            }
        }
        return;
    }

    const wl_status_t status = WiFi.status();
    if (status == WL_CONNECTED)
    {
        if (!wifiWasConnected_)
        {
            wifiWasConnected_ = true;
            onWiFiConnected();
        }
        return;
    }

    if (wifiWasConnected_)
    {
        wifiWasConnected_ = false;
        reconcileVoiceRuntimeState();
        LOG_WARNING("Log", "WiFi disconnected, status=%s(%d)", wifiStatusToText(status), status);
    }

    if (!wifiReconnectActive_)
    {
        return;
    }

    if (wifiConnectAttemptStartedMs_ != 0)
    {
        const uint32_t attemptElapsedMs = nowMs - wifiConnectAttemptStartedMs_;
        if (shouldFinishWiFiAttempt(status, attemptElapsedMs))
        {
            LOG_WARNING("Log", "WiFi attempt failed after %u ms, status=%s(%d), last_disconnect_reason=%u",
                        (unsigned)attemptElapsedMs,
                        wifiStatusToText(status),
                        status,
                        static_cast<unsigned>(wifiLastDisconnectReason_.load()));
            WiFi.disconnect(false, false);
            wifiConnectAttemptStartedMs_ = 0;
            wifiNextRetryAtMs_ = nowMs + kWifiRetryIntervalMs;
        }
        return;
    }

    if (nowMs < wifiNextRetryAtMs_)
    {
        return;
    }

    if (!ConnectToWiFi(configuration_.settings_.wifi_ssid, configuration_.settings_.wifi_password))
    {
        wifiNextRetryAtMs_ = nowMs + kWifiRetryIntervalMs;
    }
}

void MainTask::launchWindowsTarget(const char *target)
{
    if (target == nullptr || target[0] == '\0')
    {
        LOG_WARNING("Launcher", "Launch target is empty");
        return;
    }
    if (!currentKeyboard_ || !currentKeyboard_->isConnected())
    {
        LOG_WARNING("Launcher", "Keyboard is not connected");
        return;
    }

    currentKeyboard_->releaseAll();
    currentKeyboard_->press(kLeftWindowsKey);
    currentKeyboard_->press(static_cast<uint8_t>('r'));
    delay(50);
    currentKeyboard_->releaseAll();

    // Give the Windows Run dialog enough time to receive the URL.
    delay(500);
    for (const char *ch = target; *ch != '\0'; ++ch)
    {
        currentKeyboard_->press(static_cast<uint8_t>(*ch));
        currentKeyboard_->release(static_cast<uint8_t>(*ch));
        delay(8);
    }

    delay(50);
    currentKeyboard_->press(kEnterKey);
    delay(30);
    currentKeyboard_->release(kEnterKey);
    LOG_INFO("Launcher", "Windows launch command sent: %s", target);
}

uint32_t MainTask::HandleCodexKeyActions(uint32_t pressed_edges)
{
    uint32_t codexMask = 0;
    for (int i = 0; i < PHYSICAL_KEY_NUM; ++i)
    {
        const uint32_t keyBit = 1UL << i;
        const KeyMapping mapping = configuration_.getKeyMapping(i + 1);
        CodexTask task;
        if (!lookupCodexTask(mapping.function_key, task))
        {
            continue;
        }

        codexMask |= keyBit;
        if ((pressed_edges & keyBit) == 0)
        {
            continue;
        }

        if (codexBridge_.QueueTask(task))
        {
            LOG_INFO("Codex", "Queued task from K%d", i + 1);
        }
        else
        {
            LOG_WARNING("Codex", "Host unavailable or task queue full for K%d", i + 1);
        }
    }
    return codexMask;
}

void MainTask::handleKeyEvent(uint32_t key_value, uint32_t pressed_edges)
{
    const uint32_t codexMask = HandleCodexKeyActions(pressed_edges);
    key_value &= ~codexMask;
    pressed_edges &= ~codexMask;
    SendDisplayKeyInput(key_value);

    if (key_value == 0)
    {
        if (currentKeyboard_)
        {
            currentKeyboard_->releaseAll();
        }
        return;
    }

    if (!currentKeyboard_)
    {
        LOG_ERROR("Log", "No keyboard initialized");
        return;
    }

    // 检查键盘连接状态
    if (!currentKeyboard_->isConnected())
    {
        static uint32_t last_warning_time = 0;
        uint32_t current_time = millis();

        // 限制警告频率，避免日志刷屏
        if (current_time - last_warning_time > 5000)
        {
            if (currentWorkMode_ == Configuration::WIRED_KEYBOARD_MODE)
            {
                LOG_WARNING("Log", "USB keyboard not connected to host - keys ignored");
            }
            else if (currentWorkMode_ == Configuration::BLUETOOTH_KEYBOARD_MODE)
            {
                LOG_WARNING("Log", "BLE keyboard not connected to host - keys ignored");
            }
            last_warning_time = current_time;
        }
        return;
    }

    uint32_t temp_key_value = key_value;

    // 先释放所有按键，然后按新按下的键
    currentKeyboard_->releaseAll();

    // 主键盘按键处理
    for (int i = 0; i < PHYSICAL_KEY_NUM; i++)
    {
        if (temp_key_value & 0x01)
        {
            // 按下按键
            KeyMapping mapping = configuration_.getKeyMapping(i + 1);
            // 先处理宏键
            if (mapping.macros_key_count > 0)
            {
                for (int n = 0; n < mapping.macros_key_count; n++)
                {
                    currentKeyboard_->press(mapping.macros_key[n]);
                    LOG_DEBUG("Log", "[Keyboard] Set Macros Key 0x%02X", mapping.macros_key[n]);
                }
            }

            // 再处理普通键
            if (mapping.function_key.isEmpty())
            {
                if (mapping.normal_key_count > 0)
                {
                    for (int n = 0; n < mapping.normal_key_count; n++)
                    {
                        currentKeyboard_->press(mapping.normal_key[n]);
                        LOG_DEBUG("Log", "[Keyboard] Set Normal Key 0x%02X", mapping.normal_key[n]);
                    }
                }
            }
            else
            {
                const char *launchTarget = lookupWindowsLaunchTarget(mapping.function_key);
                if (launchTarget != nullptr)
                {
                    if (pressed_edges & (1UL << i))
                    {
                        launchWindowsTarget(launchTarget);
                    }
                }
                else if (!mapping.function_key.equals(kVoiceTriggerFunctionKey))
                {
                    currentKeyboard_->press(mapping.function_key);
                    LOG_DEBUG("Log", "[Keyboard] Set Function Key %s", mapping.function_key.c_str());
                }
            }
        }
        temp_key_value = temp_key_value >> 1;
    }

    LOG_DEBUG("Log", "Key event processed successfully (key_value: 0x%08X)", key_value);
}

void MainTask::updateVoiceTriggerBitFromKeymap()
{
    uint32_t triggerMask = 0;
    for (int i = 0; i < PHYSICAL_KEY_NUM; ++i)
    {
        KeyMapping km = configuration_.getKeyMapping(i + 1);
        String functionKey = normalizeFunctionKey(km.function_key);
        if (!functionKey.isEmpty())
        {
            LOG_DEBUG("ASR", "Key%d function=%s", i + 1, functionKey.c_str());
        }
        if (functionKey.equalsIgnoreCase(kVoiceTriggerFunctionKey))
        {
            triggerMask |= (1UL << i);
        }
    }

    voiceTriggerBit_ = triggerMask;
    if (voiceTriggerBit_ != 0)
    {
        LOG_INFO("ASR", "Voice trigger source: %s (mask=0x%08X)", kVoiceTriggerFunctionKey, voiceTriggerBit_);
    }
    else
    {
        LOG_WARNING("ASR", "No %s mapping found in first %d physical keys, ASR trigger disabled",
                    kVoiceTriggerFunctionKey,
                    PHYSICAL_KEY_NUM);
    }
}

void MainTask::applyVoiceConfig()
{
    updateVoiceTriggerBitFromKeymap();

    VoiceRecognizer::Config cfg;
    cfg.baiduApiKey = configuration_.settings_.voice_baidu_api_key;
    cfg.baiduSecretKey = configuration_.settings_.voice_baidu_secret_key;
    cfg.cuid = configuration_.settings_.voice_cuid;
    cfg.devPid = configuration_.settings_.voice_dev_pid;
    int cfgMs = configuration_.settings_.voice_max_record_ms;
    if (cfgMs < 1000)
        cfgMs = 1000;
    if (cfgMs > 8000)
        cfgMs = 8000;
    cfg.maxRecordMs = static_cast<uint32_t>(cfgMs);
    voiceRecognizer_.setConfig(cfg);
}

void MainTask::reconcileVoiceRuntimeState()
{
    const bool shouldEnableVoice = configuration_.settings_.voice_enable &&
                                   currentWorkMode_ == Configuration::WIRED_KEYBOARD_MODE &&
                                   WiFi.status() == WL_CONNECTED;

    if (!shouldEnableVoice)
    {
        if (voiceCaptureActive_ || voiceRecognizer_.isCapturing())
        {
            SendAsrRecordingState(false);
            voiceCaptureActive_ = false;
            voiceRecognitionBusy_ = false;
        }
        voiceRecognizer_.suspend();
        return;
    }

    if (!voiceRecognizerStarted_)
    {
        if (!voiceRecognizer_.begin())
        {
            LOG_WARNING("ASR", "VoiceRecognizer init failed, feature disabled");
            return;
        }
        voiceRecognizerStarted_ = true;
    }
    else if (!voiceRecognizer_.resume())
    {
        LOG_WARNING("ASR", "VoiceRecognizer resume failed");
        return;
    }

}

void MainTask::startVoiceCapture()
{
    if (voiceRecognitionBusy_)
    {
        return;
    }

    if (!configuration_.settings_.voice_enable)
    {
        return;
    }

    if (currentWorkMode_ != Configuration::WIRED_KEYBOARD_MODE)
    {
        LOG_WARNING("ASR", "Voice typing requires wired USB mode");
        return;
    }

    if (WiFi.status() != WL_CONNECTED)
    {
        LOG_WARNING("ASR", "WiFi is not connected, skip voice recognition");
        return;
    }

    voiceRecognitionBusy_ = true;
    if (!voiceRecognizer_.startCapture())
    {
        LOG_ERROR("ASR", "Voice capture start failed");
        voiceRecognitionBusy_ = false;
        return;
    }

    voiceCaptureActive_ = true;
    SendAsrRecordingState(true);
    LOG_INFO("ASR", "Voice trigger pressed, start capture");
}
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

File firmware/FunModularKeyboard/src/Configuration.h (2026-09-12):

#pragma once
#include <Arduino.h>
#include <SPIFFS.h>
#include <SimpleIni.h>
#include <freertos/FreeRTOS.h>
#include <freertos/semphr.h>
#include "MatrixScanner.h"
#include "LogManager.h"

#define CONFIG_ALL_KEY_NUM 26 // 包含其他模块的按键总数量
#define CONFIG_PROFILE_COUNT 8

struct KeyMapping
{
    String function_key{};
    uint8_t normal_key[6]; // Up to 6 normal keys
    uint8_t macros_key[5]; // Up to 5 macros keys
    uint8_t normal_key_count = 0;
    uint8_t macros_key_count = 0;
};

struct DeviceSettings
{
    bool wifi_switch = 0;  // 0关闭wifi，1连接wifi
    String wifi_ssid = "";
    String wifi_password = "";
    int work_mode = 0; // enum WORKMODE
    int rgb_mode = 0;  // enum RGB_MODE，为0，则代表关闭LED背景显示，不影响按键点击显示效果，否则按照模式显示rgb
    String rgb_single_colar = "0";
    int rgb_click_mode = 0;  // enum RGB_CLICK_MODE,单个按键点击后配置的显示颜色
    int rgb_brightness = 80; // 0~100
    int tft_theme = 1;       // 1~3
    int tft_brightness = 80; // 5~100
    int device_volume = 50;  // 0~100
    int power_mode = 0;      // enum POWER_MODE

    bool voice_enable = 1;
    int voice_trigger_key = 16;     // 1-based physical key index
    int voice_max_record_ms = 6000; // max hold duration
    int voice_auto_enter = 1;
    int voice_dev_pid = 1537;
    String voice_cuid = "FunModularKeyboard";
    String voice_baidu_api_key = "";
    String voice_baidu_secret_key = "";
    uint8_t active_keymap_profile = 0;
};

class Configuration
{
public:
    enum KEY_TYPE
    {
        NORMAL_KEY = 0,
        MACROS_KEY,
        FUNCTION_KEY,
    };

    enum WORK_MODE
    {
        WIRED_KEYBOARD_MODE = 0,
        BLUETOOTH_KEYBOARD_MODE,
        WIRELESS_2_4G_KEYBOARD_MODE,
        NONE_MODE,
    };

    enum RGB_MODE
    {
        RGB_NONE_MODE = 0,
        RGB_SINGLE_MODE,
        RGB_RAINBOW_MODE,
        RGB_RAINBOWWARE_MODE,
        RGB_COLORCYCLE_MODE,
        RGB_METER_MODE,
        RGB_FIRE_MODE,
        RGB_PULSE_MODE,
    };

    enum RGB_CLICK_MODE
    {
        CLICK_NONE_COLOR_MODE = 0,
        CLICK_SINGLE_COLOR_MODE,
        CLICK_WARE_COLOR_MODE,
    };

    enum POWER_MODE
    {
        NORMAL_POWER_MODE = 0, // 正常模式
        LOW_POWER_MODE,        // 低功耗模式:关闭rgb和屏幕等耗电模块
        LIGHT_POWER_MODE,      // 浅休眠模式：短暂暂停功能，可快速恢复
        DEEPSLEEP_POWER_MODE,  // 深度休眠模式：适合长时间待机
    };

public:
    Configuration();
    ~Configuration();

    bool load(const char *path = "/config.ini");
    bool SaveKeyMapping(const char *path = "/config.ini");
    bool SaveSetting(const char *path = "/config.ini");
    bool loadActiveProfileKeyMapping(const char *fallbackPath = "/config.ini");
    static String getProfileConfigPath(uint8_t profileIndex);

    void InitSPIFFS();
    String getDeviceName() const { return device_name_; }
    DeviceSettings &getSettings() { return settings_; }
    KeyMapping getKeyMapping(uint8_t physical_key) const;
    bool parseKeyMapping(Configuration::KEY_TYPE key_type, const String &value, KeyMapping &mapping);
    bool writeSection(CSimpleIniA &ini, const char *section);

    // 辅助函数：加载配置但不解析，只用于保存
    bool loadRawIni(CSimpleIniA &ini, const char *path);
    // 辅助函数：保存INI到文件
    bool saveIniToFile(CSimpleIniA &ini, const char *path);

    SemaphoreHandle_t mutex_;
    String device_name_;
    String device_id_;
    String firmware_version_;
    KeyMapping key_mappings_[CONFIG_ALL_KEY_NUM];
    DeviceSettings settings_;

    int all_key_num_{16};
};

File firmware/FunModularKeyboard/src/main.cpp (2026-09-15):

#include <Arduino.h>
#include "MainTask.h"
#include "Configuration.h"
#include "DisplayTask.h"
#include "SPIFFS.h"
#include "LogManager.h"
#include "SystemTime.h"

// 配置
Configuration config;

// 创建消息队列
QueueHandle_t displayQueue = xQueueCreate(10, sizeof(DisplayMessage));

static DisplayTask display_task(0);
static MainTask main_task(1, config);

// 打印系统时间
void printSystemTime()
{
    struct tm timeinfo;
    if (!getLocalTime(&timeinfo))
    {
        LOG_DEBUG("Log", "获取系统时间失败");
        return;
    }

    char timeString[64];
    strftime(timeString, sizeof(timeString), "%Y-%m-%d %H:%M:%S", &timeinfo);
    LOG_DEBUG("Log", "系统时间: ");
    LOG_DEBUG("Log", timeString);
}

void setup()
{
    // Disable the LCD backlight before logging, SPIFFS, WiFi and BLE startup.
    lvgl_hold_backlight_off();

    SystemTime::ConfigureChinaTimeZone();

    // Serial.begin(115200);

    // 初始化日志系统
    LogManager::getInstance().begin(115200);
    // 设置日志级别（只显示DEBUG及以上级别）
    LogManager::getInstance().setLogLevel(LogLevel::DEBUG);
    // 添加自定义回调
    LogManager::getInstance().addCallback([](const LogEntry &entry)
                                          {
                                              // 这里可以添加其他输出方式，如SD卡、网络等
                                              // 示例：同时输出到第二个串口（如果可用）
                                              // Serial2.println(LogManager::formatLogEntry(entry));
                                          });

    // LOG_DEBUG("Log","Flash总大小: %.2f \rMB\n", ESP.getFlashChipSize() / 1024.0 / 1024);
    // LOG_DEBUG("Log","APP分区: %.2f MB", ESP.getSketchSize() / 1024.0 / 1024);
    // LOG_DEBUG("Log","Free Space:%.2f MB", ESP.getFreeSketchSpace() / 1024.0 / 1024);
    // LOG_DEBUG("Log","SPIFFS: %.2f MB", SPIFFS.totalBytes() / 1024.0 / 1024);
    // LOG_DEBUG("Log","SPIFFS Total: %d bytes, Used: %d bytes",
    //     SPIFFS.totalBytes(), SPIFFS.usedBytes());
    // LOG_WARNING("Test", "This is a debug message");

    // // 连接 WiFi
    // if (connectToWiFi()) {
    //     // 同步 NTP 时间到系统时钟
    //     if (syncTimeFromNTP()) {
    //     LOG_DEBUG("Log", "系统时钟同步成功");
    //     }
    // }

    // // // 断开 WiFi 以节省功耗（如果需要）
    // WiFi.disconnect(true);
    // WiFi.mode(WIFI_OFF);

    // 初始化SPIFFS
    config.InitSPIFFS();

    if (!SPIFFS.begin(true))
    {
        LOG_DEBUG("Log", "SPIFFS Mount Failed!");
        return;
    }

    // 打印SPIFFS中存在的文件
    File root = SPIFFS.open("/");
    LOG_DEBUG("Log", "SPIFFS file:");
    while (File file = root.openNextFile())
    {
        LOG_DEBUG("Log", file.name());
    }

    // 加载配置文件
    if (config.load())
    {
        LOG_DEBUG("Log", "Config loaded:");
        LOG_DEBUG("Log", "Device: " + config.getDeviceName());
    }

    // 设置消息队列
    display_task.setMessageQueue(displayQueue);
    main_task.setMessageQueue(displayQueue);

    // 启动任务
    //  先启动主任务，给 BLE/WiFi 初始化预留更多可用内存。
    main_task.begin();

    // BLE mode may briefly use WiFi to obtain NTP time. Keep LVGL from taking
    // internal heap until the keyboard stack has finished initialization.
    const uint32_t startupWaitStartedMs = millis();
    constexpr uint32_t kMainTaskStartupTimeoutMs = 22000;
    while (!main_task.IsStartupReady() && millis() - startupWaitStartedMs < kMainTaskStartupTimeoutMs)
    {
        delay(20);
    }
    display_task.begin();
}

void loop()
{
    // Arduino主循环通常为空，因为任务在FreeRTOS中运行
    vTaskDelay(portMAX_DELAY);
}

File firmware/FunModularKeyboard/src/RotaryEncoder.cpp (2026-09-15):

#include "RotaryEncoder.h"

namespace
{
    constexpr uint8_t kEncoderClkPin = 5;
    constexpr uint8_t kEncoderDtPin = 21;
    constexpr uint8_t kEncoderSwitchPin = 9;
    constexpr int8_t kTransitionsPerDetent = 4;
    constexpr uint32_t kButtonDebounceMs = 25;
    constexpr uint32_t kButtonLongPressMs = 700;

    // Quadrature state table: previous AB in bits 3:2, current AB in bits 1:0.
    constexpr int8_t kTransitionTable[16] = {
        0, 1, -1, 0,
        -1, 0, 0, 1,
        1, 0, 0, -1,
        0, -1, 1, 0};
}

void RotaryEncoder::Begin()
{
    pinMode(kEncoderClkPin, INPUT_PULLUP);
    pinMode(kEncoderDtPin, INPUT_PULLUP);
    pinMode(kEncoderSwitchPin, INPUT_PULLUP);

    lastRotationState_ = (static_cast<uint8_t>(digitalRead(kEncoderClkPin)) << 1) |
                         static_cast<uint8_t>(digitalRead(kEncoderDtPin));
    lastRawButtonPressed_ = digitalRead(kEncoderSwitchPin) == LOW;
    stableButtonPressed_ = lastRawButtonPressed_;
    buttonChangedAtMs_ = millis();
    buttonPressedAtMs_ = 0;
    longPressEmitted_ = false;
    rotationAccumulator_ = 0;
    initialized_ = true;
}

void RotaryEncoder::Loop()
{
    if (!initialized_)
    {
        return;
    }

    CheckRotation();
    CheckButton();
}

void RotaryEncoder::SetCallback(Callback callback, void *context)
{
    callback_ = callback;
    callbackContext_ = context;
}

void RotaryEncoder::CheckRotation()
{
    const uint8_t currentState = (static_cast<uint8_t>(digitalRead(kEncoderClkPin)) << 1) |
                                 static_cast<uint8_t>(digitalRead(kEncoderDtPin));
    if (currentState == lastRotationState_)
    {
        return;
    }

    const uint8_t transition = static_cast<uint8_t>((lastRotationState_ << 2) | currentState);
    lastRotationState_ = currentState;
    rotationAccumulator_ += kTransitionTable[transition];

    if (rotationAccumulator_ >= kTransitionsPerDetent)
    {
        rotationAccumulator_ = 0;
        Emit(RotaryAction::CLOCKWISE);
    }
    else if (rotationAccumulator_ <= -kTransitionsPerDetent)
    {
        rotationAccumulator_ = 0;
        Emit(RotaryAction::COUNTERCLOCKWISE);
    }
}

void RotaryEncoder::CheckButton()
{
    const bool rawPressed = digitalRead(kEncoderSwitchPin) == LOW;
    const uint32_t nowMs = millis();

    if (rawPressed != lastRawButtonPressed_)
    {
        lastRawButtonPressed_ = rawPressed;
        buttonChangedAtMs_ = nowMs;
    }

    if (rawPressed != stableButtonPressed_ &&
        static_cast<uint32_t>(nowMs - buttonChangedAtMs_) >= kButtonDebounceMs)
    {
        stableButtonPressed_ = rawPressed;
        if (stableButtonPressed_)
        {
            buttonPressedAtMs_ = nowMs;
            longPressEmitted_ = false;
        }
        else if (!longPressEmitted_)
        {
            Emit(RotaryAction::CLICK);
        }
    }

    if (stableButtonPressed_ && !longPressEmitted_ &&
        static_cast<uint32_t>(nowMs - buttonPressedAtMs_) >= kButtonLongPressMs)
    {
        longPressEmitted_ = true;
        Emit(RotaryAction::LONG_PRESS);
    }
}

void RotaryEncoder::Emit(RotaryAction action)
{
    if (callback_ != nullptr)
    {
        callback_(action, callbackContext_);
    }
}

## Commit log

2026-08-13 Fix the issue where the host computer cannot configure buttons
2026-09-06 禁用扩展模块
2026-09-06 /src文件夹下代码格式统一化修改
    [Configuration.h]
2026-09-06 添加电源显示功能
2026-09-06 readme文件修改
2026-09-09 修复头文件引用报错和屏幕不亮问题
2026-09-10 时间显示修复
2026-09-11 删除模块A和模块B部分代码
    [Configuration.h]
2026-09-11 删除Home Assistant界面
2026-09-11 删除PC status界面
    [Configuration.h]
2026-09-11 删除上位机部分代码
    [Configuration.h]
2026-09-12 代码体积压缩
2026-09-12 删除键盘配置和系统配置界面
    [Configuration.h]
2026-09-12 修改旋钮功能为控制音量大小
2026-09-14 增加codex状态交互
2026-09-15 增加codex按键交互功能
2026-09-15 增加开机动画
2026-10-01 完善 Codex 桥接与 WiFi 重连，移除电量显示
